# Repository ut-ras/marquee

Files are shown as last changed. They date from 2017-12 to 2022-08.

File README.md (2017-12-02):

# marquee
Code for displaying things on the marquee in the RAS room

To change the text displayed, just open up a `make uart` screen and enter in your text. No backspaces, and Enter will send the text.

To change the default message, change the buffer in main.c and change `buffer_index` to one less than the message length.

To change the scroll speed, mess with the constant that multiplies the last parameter to CallEveryUS (in ShiftRunUS) towards the end of shifter.c.

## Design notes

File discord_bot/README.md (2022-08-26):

# Discord Bot for the Marquee

This is the code for the discord bot that controls the marquee. It runs off of a Flask backend.

The current plan is to host both the discord bot and the Flask app of of a free web token on Heroku.

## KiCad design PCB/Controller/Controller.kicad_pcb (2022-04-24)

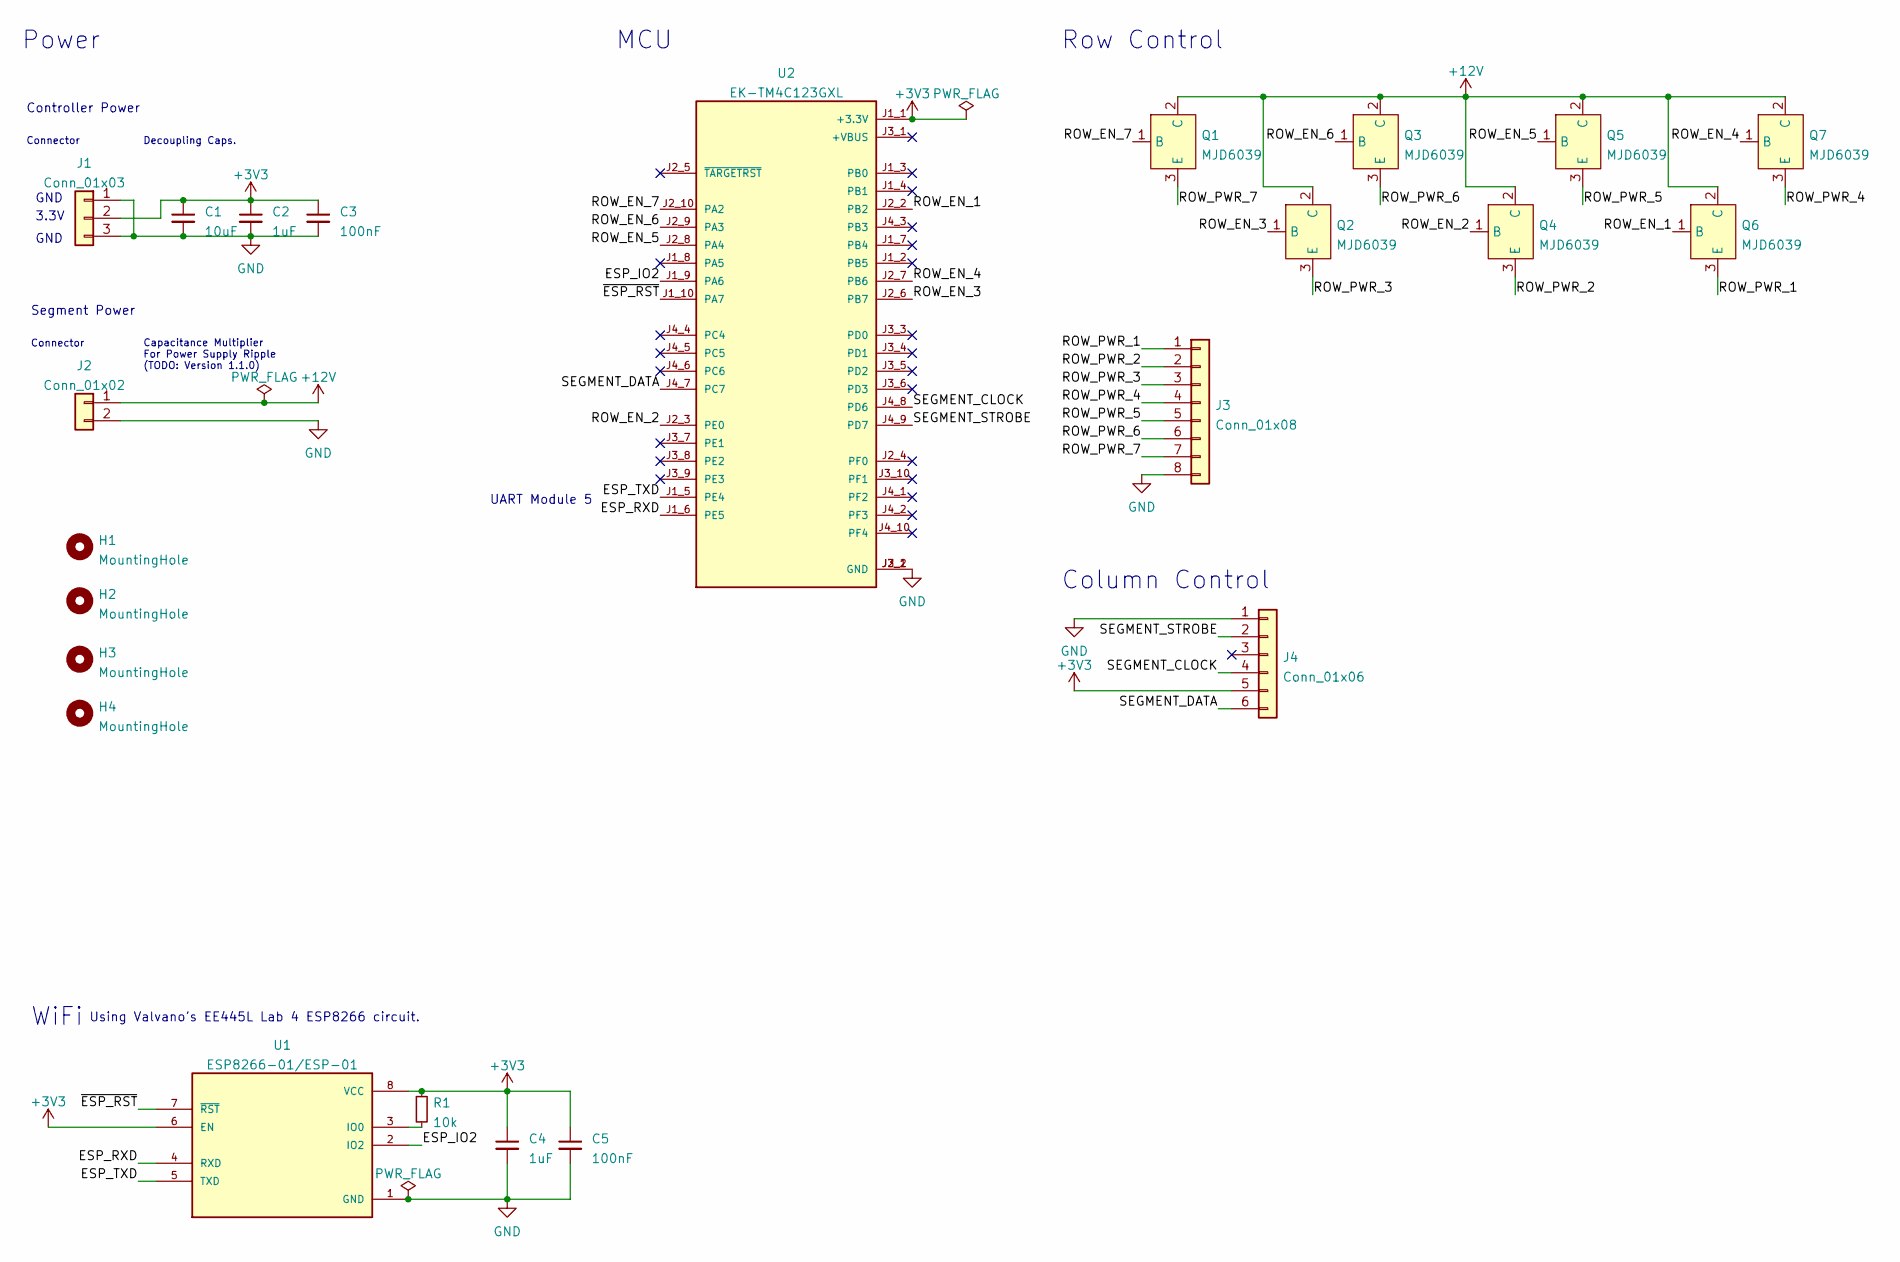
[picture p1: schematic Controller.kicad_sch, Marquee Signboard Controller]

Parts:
C1: 10uF; C_0805_2012Metric; Part Number CL21A106KAYNNNE; JLCPCB BOM 1
C2, C4: 1uF; C_0805_2012Metric; Part Number CL21B105KBFNNNE; JLCPCB BOM 1
C3, C5: 100nF; C_0805_2012Metric; Part Number CC0805KRX7R9BB104; JLCPCB BOM 1
H1, H2, H3, H4: MountingHole; MountingHole_2.2mm_M2
J1: Conn_01x03; PinHeader_1x03_P2.54mm_Vertical
J2: Conn_01x02; SolderWire-2.5sqmm_1x02_P7.2mm_D2.4mm_OD3.6mm
J3: Conn_01x08; SolderWire-2sqmm_1x08_P7.8mm_D2mm_OD3.9mm
J4: Conn_01x06; SolderWire-2.5sqmm_1x06_P8.8mm_D2.4mm_OD4.4mm
Q1, Q2, Q3, Q4, Q5, Q6, Q7: MJD6039; TO-252-3_TabPin2; Part Number MJD6039T4G; JLCPCB BOM 0
R1: 10k; R_0805_2012Metric; Part Number 0805W8F510KT5E; JLCPCB BOM 1
U1: ESP8266-01/ESP-01; XCVR_ESP8266-01_ESP-01; Part Number WRL-17146; JLCPCB BOM 0
U2: EK-TM4C123GXL; MODULE_EK-TM4C123GXL; Part Number EK-TM4C123GXL; JLCPCB BOM 0

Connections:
+3V3: C1.1, C2.1, C3.1, C4.1, C5.1, J1.2, J4.5, R1.1, U1.6 (EN), U1.8 (VCC), U2.J1_1 (+3.3V)
+12V: J2.1, Q1.2 (C), Q2.2 (C), Q3.2 (C), Q4.2 (C), Q5.2 (C), Q6.2 (C), Q7.2 (C)
/ESP_IO2: U1.2 (IO2), U2.J1_9 (PA6)
/ESP_RXD: U1.4 (RXD), U2.J1_6 (PE5)
/ESP_TXD: U1.5 (TXD), U2.J1_5 (PE4)
/ROW_EN_1: Q6.1 (B), U2.J2_2 (PB2)
/ROW_EN_2: Q4.1 (B), U2.J2_3 (PE0)
/ROW_EN_3: Q2.1 (B), U2.J2_6 (PB7)
/ROW_EN_4: Q7.1 (B), U2.J2_7 (PB6)
/ROW_EN_5: Q5.1 (B), U2.J2_8 (PA4)
/ROW_EN_6: Q3.1 (B), U2.J2_9 (PA3)
/ROW_EN_7: Q1.1 (B), U2.J2_10 (PA2)
/ROW_PWR_1: J3.1, Q6.3 (E)
/ROW_PWR_2: J3.2, Q4.3 (E)
/ROW_PWR_3: J3.3, Q2.3 (E)
/ROW_PWR_4: J3.4, Q7.3 (E)
/ROW_PWR_5: J3.5, Q5.3 (E)
/ROW_PWR_6: J3.6, Q3.3 (E)
/ROW_PWR_7: J3.7, Q1.3 (E)
/SEGMENT_CLOCK: J4.4, U2.J4_8 (PD6)
/SEGMENT_DATA: J4.6, U2.J4_7 (PC7)
/SEGMENT_STROBE: J4.2, U2.J4_9 (PD7)
/~ESP_RST: U1.7 (~RST), U2.J1_10 (PA7)
GND: C1.2, C2.2, C3.2, C4.2, C5.2, J1.1, J1.3, J2.2, J3.8, J4.1, U1.1 (GND), U2.J2_1 (GND), U2.J3_2 (GND)
unnamed: R1.2, U1.3 (IO0)

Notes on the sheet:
Controller Power
Row Control
Connector
Column Control
Capacitance Multiplier For Power Supply Ripple (TODO: Version 1.1.0)
GND
Decoupling Caps.
Using Valvano's EE445L Lab 4 ESP8266 circuit.
UART Module 5
Segment Power
3.3V
Power
MCU
WiFi

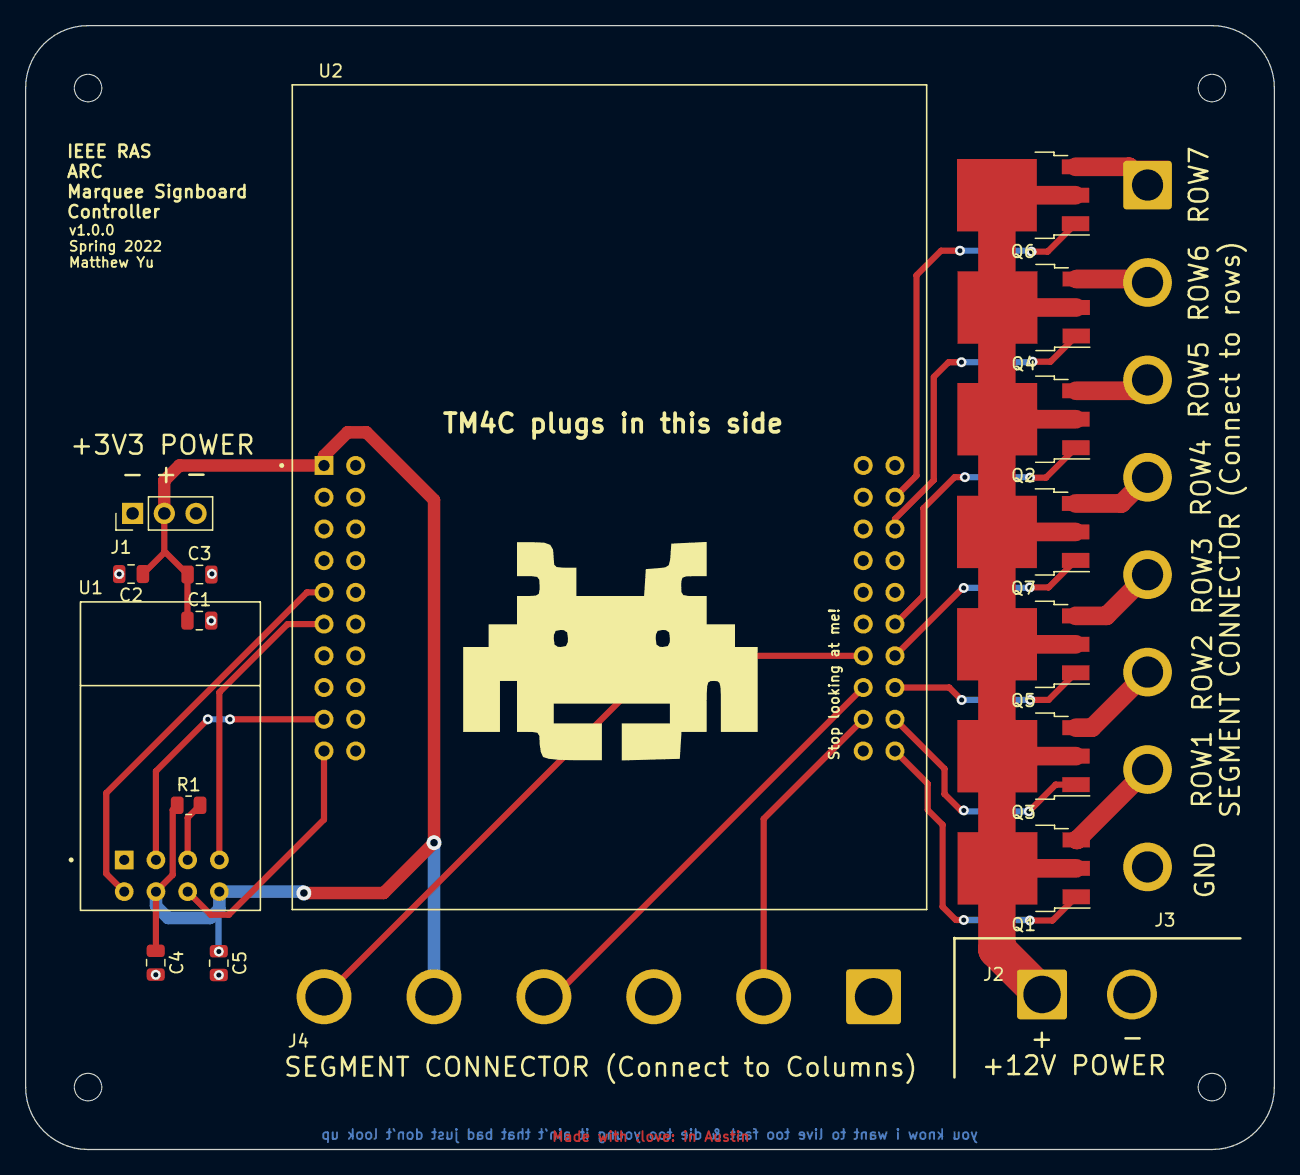
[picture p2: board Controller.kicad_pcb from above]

Board: 2 copper layers, 100.0 x 90.0 mm, 23 parts (0 on the bottom side), 25 nets.

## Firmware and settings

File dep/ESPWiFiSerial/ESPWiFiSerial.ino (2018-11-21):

/* ESP8266 WiFi Serial Tool
 * based on https://github.com/ut-ras/ESP8266_Arduino_Examples
 *
 *  Sets up the ESP8266 as a WiFi Access Point or connects to one
 *  Launches a Web Server with a form to output text over Serial
 *
 *  AP Mode: Launches the web server at http://192.168.4.1:80/
 *  STA Mode: Connects to an existing WiFi network
 *
 * Web Server
 * https://github.com/esp8266/Arduino/tree/master/libraries/ESP8266WebServer/examples/HelloServer
 * https://links2004.github.io/Arduino/d3/d58/class_e_s_p8266_web_server.html
 * https://github.com/esp8266/Arduino/blob/master/libraries/ESP8266WebServer/src/ESP8266WebServer.h
 * Examples > ESP8266WebServer
 *
 * Soft Access Point
 * https://arduino-esp8266.readthedocs.io/en/latest/esp8266wifi/soft-access-point-class.html
 */

#include <ESP8266WiFi.h>
#include <WiFiClient.h>
#include <ESP8266WebServer.h>

#include "clock.h"


/* WiFi Mode
 * STA = connect to a WiFi network with name ssid
 * AP = create a WiFi access point with  name ssid
 */
#define WIFI_MODE "AP"
const char * ssid = "RAS_Signboard";
const char * pass = "esp";



//Web Server at port 80
int port = 80;
IPAddress ip;
String webServerPath = "http://";
ESP8266WebServer server(port);


//Marquee Default Message
String default_mssg = "Welcome to IEEE RAS!";


//Marquee Current Info
String current_mssg = default_mssg;
boolean clock_display = false;      //turn the clock on, only do this if connected to WiFi and time sync
int last_t = 0;         //for timing each minute to update display



/* Setup Functions */

/* setupWiFi
 * STA = connect to a WiFi network with name ssid
 * AP = create a WiFi access point with  name ssid
 */
void setupWiFi(String mode, const char * _ssid, const char * _pass) {
  if (mode.equals("AP")) {
    //Turn on Access Point
    WiFi.softAP(_ssid, _pass);
    ip = WiFi.softAPIP();
  }
  else {
    //Connect to a WiFi network
    WiFi.mode(WIFI_STA);
    WiFi.begin(_ssid, _pass);
    while (WiFi.status() != WL_CONNECTED) {
      delay(500);
      yield();
      //Serial.print(".");
    }
    ip = WiFi.localIP();
  }
}

void setupWebServer() {
  //Turn on a web server at port 80
  //Map paths to hander functions, can also specify HTTP methods
  server.on("/", handleRoot);
  server.on("/serial", HTTP_POST, handleSerial);
  server.on("/serial", HTTP_GET, handleRoot);
  server.onNotFound(handleNotFound);    //404 Not Found
  server.begin();

  webServerPath += ip.toString() + ":" + String(port) + "/";
}

void setup() {
  Serial.begin(115200);

  setupWiFi(WIFI_MODE, ssid, pass);
  setupWebServer();
  
  //Serial.println("WiFi mode=" + String(WIFI_MODE) + ", ssid = " + String(ssid) + ", pass = " + String(pass));
  //Serial.println("Web server at " + webServerPath);

  //only set clock_display on if in station mode
  clock_display = String(WIFI_MODE).equals("STA");
  if (clock_display) {
    //Serial.println("Setting up time sync");
    setupTime();

    last_t = millis() - (1000 * getSecond() ) + 1000;    //so the minutes are updated 1 s after minute changes
  }

  //send default message
  serialMarquee(default_mssg);
}





/* Main Loop - Handle a client connection */
void loop() {
  
  //check the clock if its on
  checkClock();
  
  //handle web server
  server.handleClient();
  
}


//marquee serial output format
void serialMarquee(String mssg) {
  //Check clock
  if (clock_display && isTimeSync()) {
    mssg = getClock() + " " + mssg;
  }
  
  //Marquee must receive 25 characters for scrolling
  while(mssg.length() < 26) {
    mssg = mssg + " ";
  }
  mssg += "\n";
  Serial.print(mssg);
}

//check if clock needs to be updated and resend current message
void checkClock() {
  if ((clock_display) && (millis() - last_t >= 1000 * 60)) {
    last_t = millis();
    serialMarquee(current_mssg);    
    //String test_datetime = getClock() + " " + getDate(false, true);
    //Serial.println(test_datetime);
  }
}




/* Request Handlers */

//main page
void handleRoot() {
  server.send(200, "text/html", indexHTML());
}

//serial posts
void handleSerial() {
  //hasArg() checks if the last HTTP request in the server has an argument
  //arg() gets the value of the arg by name

  if(server.hasArg("serial_input")) {
    String serial_input = server.arg("serial_input");
    //Serial.println(serial_input);
    current_mssg = serial_input;
    serialMarquee(current_mssg);
  }
  handleRoot();
}




/* HTML */

//index and /serial
String indexHTML() {
  String htmlPage =
            String("<body>") +
              "<h1>RAS Marquee</h1>" +
              "<h2>ESP8266 Serial Tool</h2>" +
              "<form action=\"/serial\" method=\"post\">" +
                "<input type=\"text\" name=\"serial_input\" placeholder=\"Output to ESP8266 Serial\"><br>" +
                "<input type=\"submit\" value=\"Output Serial\"><br>" +
              "</form>" +
            "</body>";
  return htmlPage;
}

//404 Not Found
void handleNotFound() {
  String message = "File Not Found\n\n";
  message += "URI: ";
  message += server.uri();
  message += "\nMethod: ";
  message += (server.method() == HTTP_GET)?"GET":"POST";
  message += "\nArguments: ";
  message += server.args();
  message += "\n";
  for (uint8_t i=0; i<server.args(); i++){
    message += " " + server.argName(i) + ": " + server.arg(i) + "\n";
  }
  server.send(404, "text/plain", message);
}

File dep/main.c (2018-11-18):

#include <RASLib/inc/common.h>
#include <RASLib/inc/gpio.h>
#include <RASLib/inc/time.h>
#include <RASLib/inc/adc.h>

#include "shifter.h"
#include "display.h"

void heartbeat(void) {
    static int blink_on = true;
    SetPin(PIN_F3, blink_on);
    blink_on = !blink_on;
}

unsigned char data[] = { 
    0 ,1 ,2 ,3 , 4 ,5 ,6 , 7, 8 ,9 ,10,11, 
    12,13,14,15, 16,17,18,19, 20,21,22,23,
    24,25,26,27, 28,29,30,31, 32,33,34,35,
    36,37,38,39, 40,41,42,43, 44,45,46,47,
    48,49,50,51, 52,53,54,55, 56,57,58,59, 
    60,61,62,63, 64,65,66,67, 68,69,70,71,
    72,73,74,75, 76,77,78,79, 80,81,82,83,
    84,85,86,87, 88,89,90,91, 92,93,94,95,
};

tPin rows[7] = { PIN_A4, PIN_A3, PIN_A2, PIN_D6, PIN_D7, PIN_A6, PIN_A5 };

tShifter sh = {
    PIN_B7, PIN_E0, PIN_B2,
    7, 96, rows, true, data
};


#define BUFFER_WIDTH 256
int buffer_index = 23;
char buffer[BUFFER_WIDTH] = "    Welcome to IEEE RAS!";


// The 'main' function is the entry point of the program
int main(void) {
    // Initialization code can go here
    CallEvery(heartbeat, 0, 1.0f);
    InitDisplay(&sh);

    //For ESP8266 Connection - UART1 PB0 PB1
    //tUART * uart1 = InitializeUARTModule(1, 115200);

    sh.cb = (void (*)(void *))DisplayUpdate;
    sh.cb_data = &sh;

    Display(&sh, buffer_index, buffer+1);
    buffer_index = 1;

    
    while (1) {
        char c = (char)Getc();

        //For ESP8266 Connection - read from UART1 instead of UART0, comment out Getc()
        //char c = (char)fGetc(uart1);

        Printf("%c", c);

        if ( c > 126 || c < 32 || buffer_index == BUFFER_WIDTH-1) {
            Printf("Sequence complete!\n");
            Display(&sh, buffer_index-1, buffer+1);
            buffer_index = 1;
        } else
            buffer[buffer_index++] = c;
    }
}

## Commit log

2015-04-16 Fixed issues with fonts and displaying long messages
    [main.c, shifter.c]
2017-12-01 Update makefile for the new world
    The only real change here is that the library search dirs are back in the linker flags (same as current Rasware). Not sure how/why this wasn't already the case.
    Also, Stellaris should be in /usr/local/lib/StellarisWare (same as Rasware)
2017-12-01 Tweaked main.c to: End on any character not defined in the font (instead of waiting for a return carriage - most computers aren't typewriters). Newlines should end messages now. Send the recieved cha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
    It's possible there was some reason why '\r' was used to terminate a message, but I can't think of one.
2017-12-08 started uart function
2017-12-08 wiringpi2 import
2017-12-08 uart working
2017-12-09 fixed uart
2018-11-18 Comments showing how to use UART1 for ESP8266 connection
2022-03-31 initial drivers for marquee. needs testing.
2022-04-02 Working on bdf parser, new controller PCB.
    [Controller.kicad_pcb, Controller.kicad_sch]
2022-04-03 sample bdf font script.
    [Controller.kicad_sch]
2022-04-04 finished v1.0.0 of marquee controller.
    [Controller.kicad_pcb, Controller.kicad_sch]
2022-04-08 Working segment example. onto font.
    [RGBSegment.kicad_pcb, RGBSegment.kicad_sch]
2022-04-08 linear display test.
    [Controller.kicad_pcb, RGBSegment.kicad_sch]
2022-04-24 latest update of pcbs
    [Controller.kicad_pcb]
2022-08-26 savestate boardchange
